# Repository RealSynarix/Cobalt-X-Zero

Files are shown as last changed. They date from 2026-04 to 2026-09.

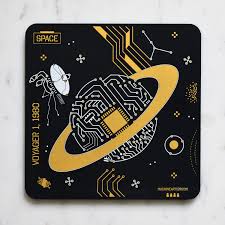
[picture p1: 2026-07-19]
docs/media/images/reference/3.jpg

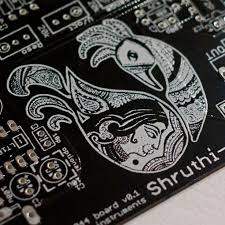
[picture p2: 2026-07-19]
docs/media/images/reference/1.jpg

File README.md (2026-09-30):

# Cobalt-X Zero

**Open-source • 3D-printable • 50g balanced gaming mouse**

Built around the STM32G431 and PixArt PMW3360.  
No bloated software. Configuration lives entirely in the browser via WebHID.

**Config site:** [Click Me :D](https://realsynarix.github.io/Cobalt-X-Zero/)  
Works in Chrome / Edge (desktop). Plug the mouse in, hit **Connect**, create or edit profiles, save.

---

## Why this exists

Most gaming mice force you to install closed, resource-heavy software.  
Cobalt-X Zero does the opposite:

- Fully open hardware & software (PCB, shell, firmware, configurator)
- Zero host-side software required after initial flash (you need software to flash, but then you can close and optionally delete it)
- Lightweight, relatively cheap, and modifiable by design

Ideal for anyone who wants a high-performance mouse without proprietary software and host resources being hogged.

---

## Specs

| Part | Detail |
|---|---|
| **MCU** | STM32G431KBT6 (170 MHz, LQFP-32) |
| **Sensor** | PixArt PMW3360 |
| **Polling** | 1000 Hz USB (8 kHz internal loop + SOF sync) |
| **Click latency**| ~2.5 ms |
| **Weight** | 50 g (without cable) |
| **Switches** | Kailh Mute Push Buttons (red cap, 2 pin + 10M click life-span) |
| **Wheel** | TTC EC10 rotary encoder + custom printed wheel |
| **LEDs** | 2× RGB (Cathode) |
| **Config** | WebHID Github Pages Website |
| **Shell** | Custom PETG 3D Print |

---

## Repository Layout

| Path | Contents |
|---|---|
| `firmware/` | C++ firmware source + pre-built binaries |
| `hardware/fabrication/pcb/` | KiCad project, Gerbers, BOM, position files |
| `hardware/fabrication/shell/` | 3D printable STLs + print settings |
| `docs/guides/` | Assembly, flashing, configuration, and general guides |

---

## Getting Started

1. **Read the docs**  
   Start with [`docs/guides/`](docs/guides/) for assembly instructions, print settings, and firmware details.

2. **Print the shell**  
   Use the STLs and recommended settings in `hardware/fabrication/shell/`.

3. **Order & assemble the PCB**  
   - Fabricate from the Gerbers in `hardware/fabrication/pcb/` (JLCPCB works well).  
   - The PMW3360 sensor must be purchased separately (e.g. AliExpress) and hand-soldered.

4. **Flash the firmware**  
   Follow the flashing guide in `docs/guides/`. Pre-built binaries are available for quick setup; source is there if you want to modify it.

5. **Configure**  
   Open the [config site](https://realsynarix.github.io/Cobalt-X-Zero/), connect the mouse, create profiles, and tune everything to your preference. Multiple profiles are supported.

---

## License & Contributions

Everything in this project is open source.  
You are free to fork, modify, improve, and share your own builds.

**Attribution is appreciated.**  
If you use Cobalt-X Zero commercially or base a project on it, please include a link back to this repository.

Issues and pull requests are always welcome.

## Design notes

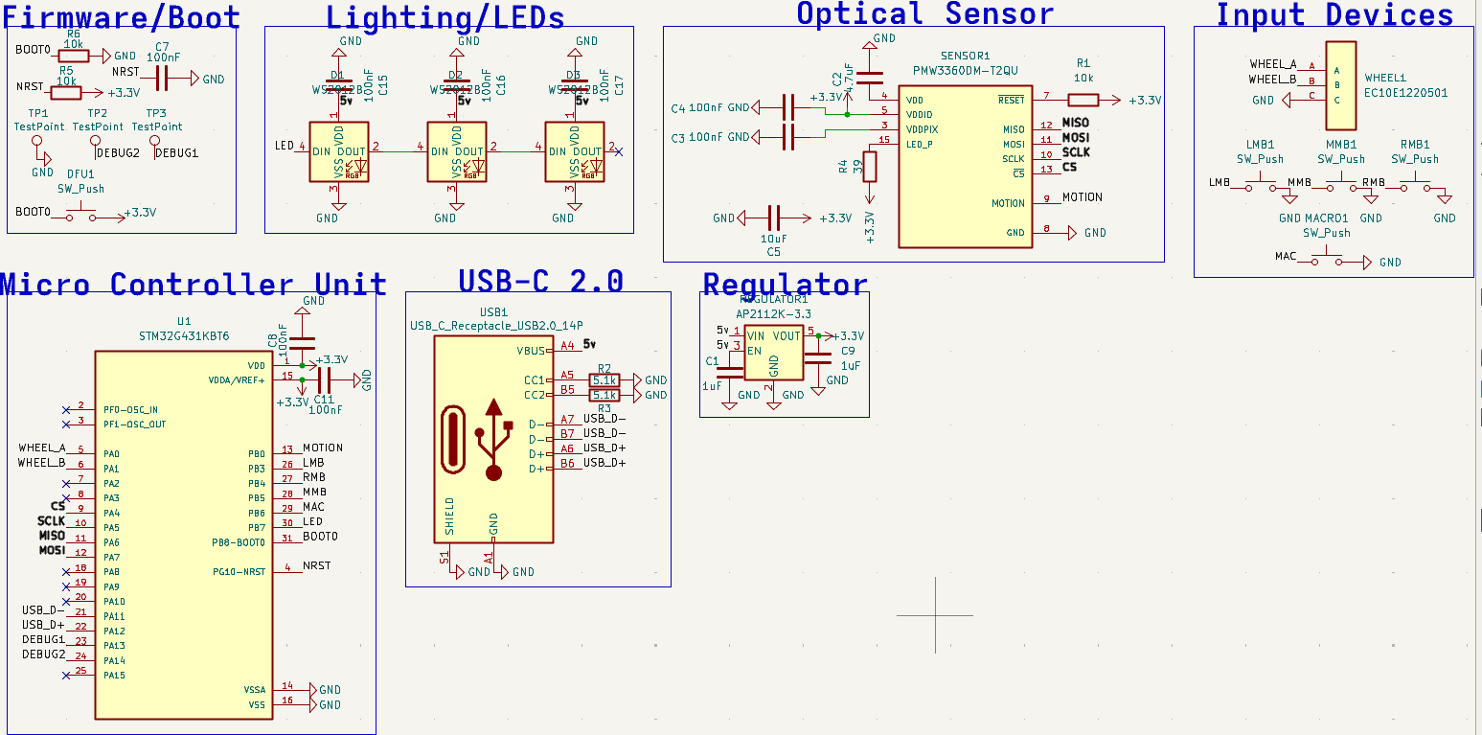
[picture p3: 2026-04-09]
docs/media/images/reference/Proto2-Schematic.png

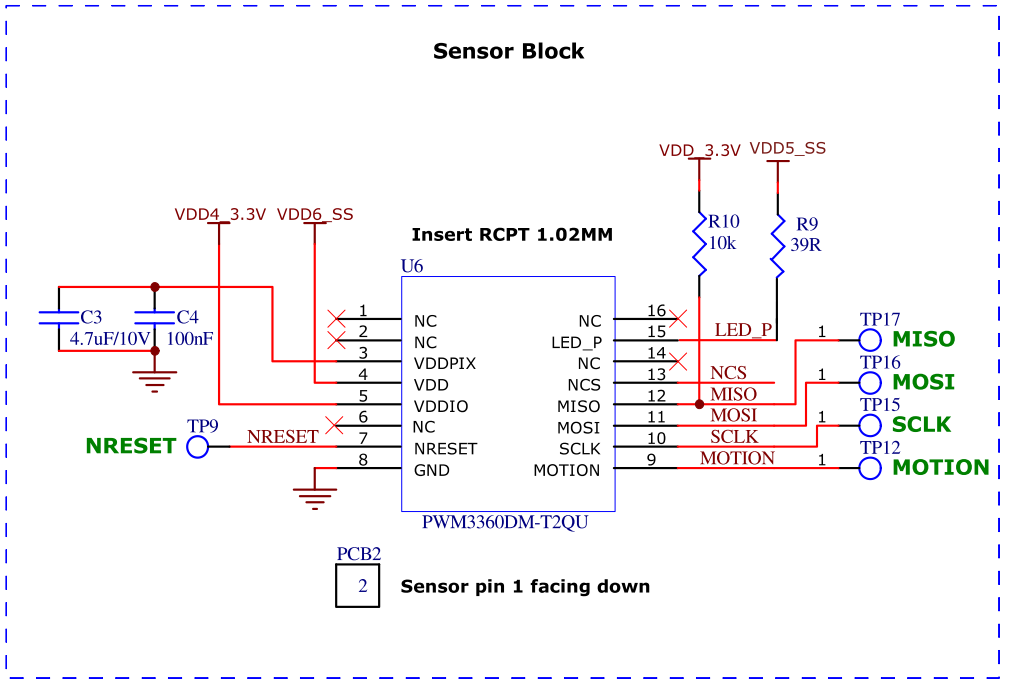
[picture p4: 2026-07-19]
docs/media/images/reference/Sensor-Block-Datasheet-Ref.png

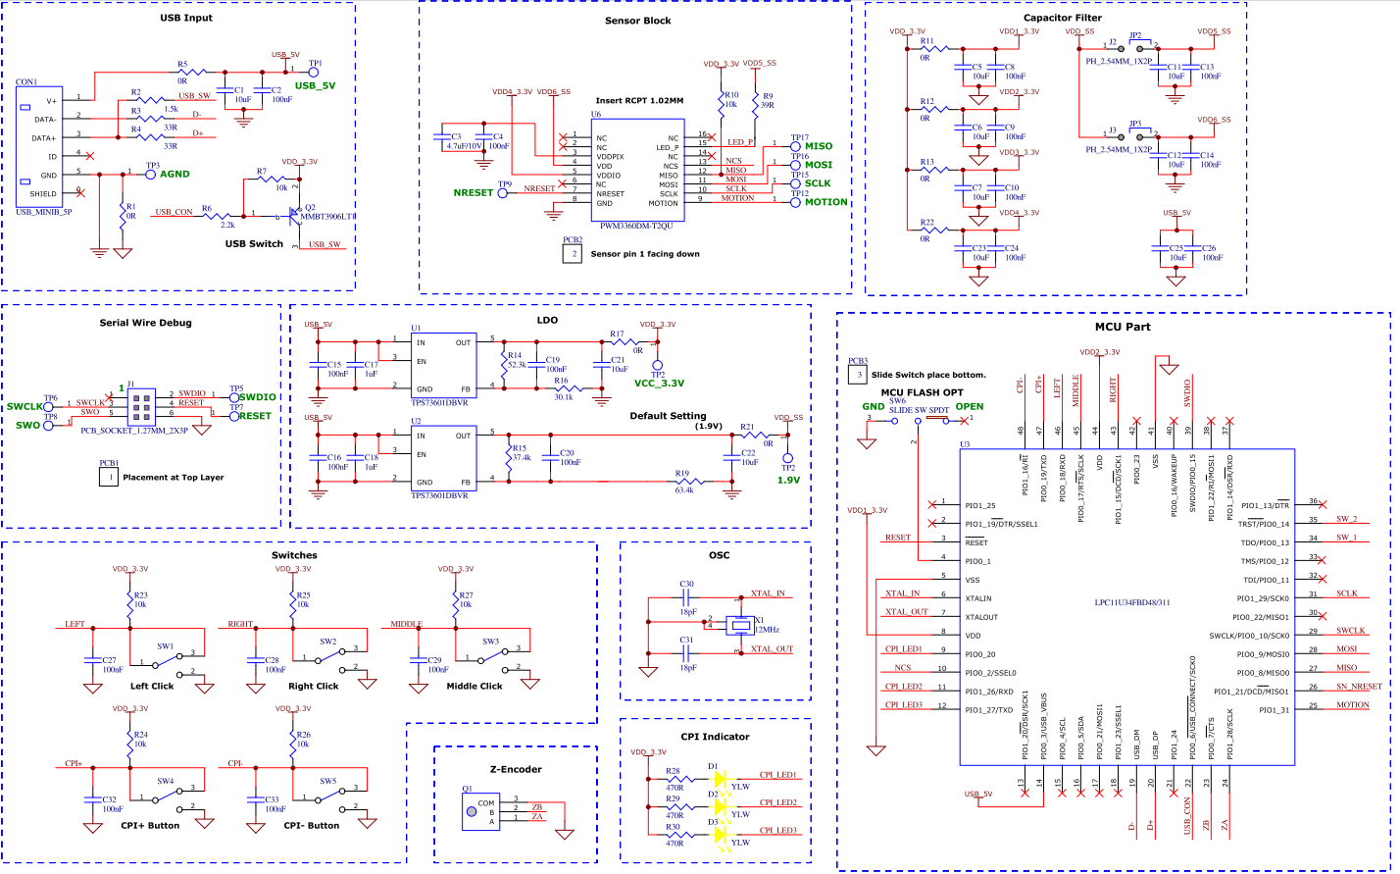
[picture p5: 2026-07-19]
docs/media/images/reference/Sensor-Schem-Datasheet-Ref.png

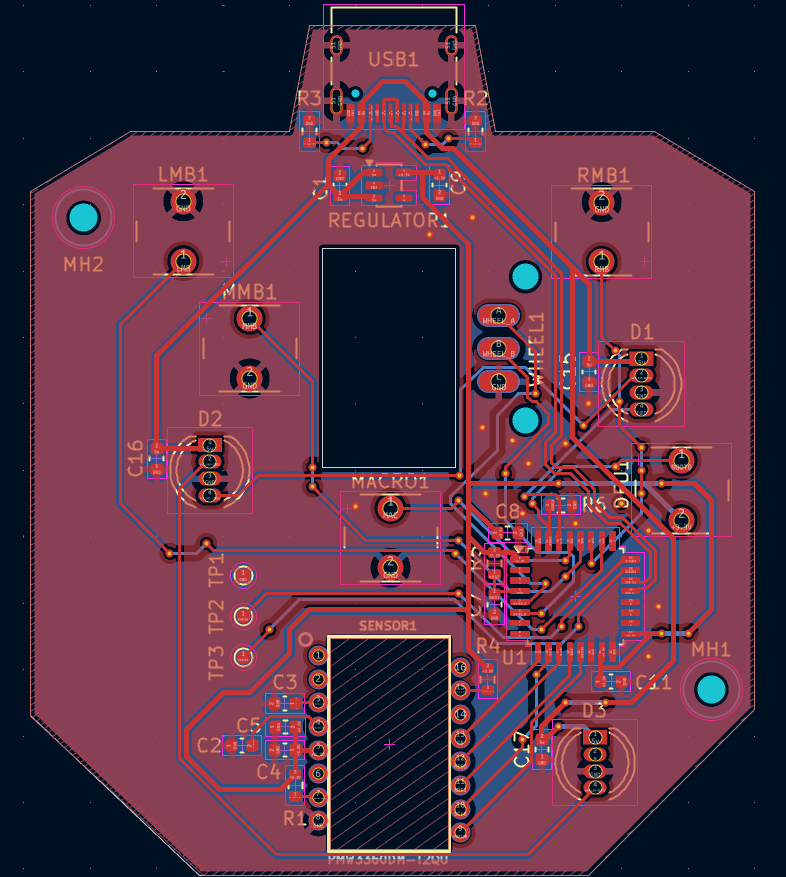
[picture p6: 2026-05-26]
docs/media/images/reference/Proto2.png

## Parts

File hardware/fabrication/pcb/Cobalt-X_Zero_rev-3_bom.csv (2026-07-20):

Designator | Footprint | Quantity | Value | LCSC Part #
C1, C10, C2, C9 | 0603 | 4 | 1uF
C11, C12, C14, C20, C7, C8 | 0603 | 6 | 100nF
C13 | 0603 | 1 | 4.7uF
C17, C3 | 0603 | 2 | 10nF
MCU1 | LQFP-32_7x7mm_P0.8mm | 1 | STM32G431KBT6
R1 | 0603 | 1 | 39
R10, R11, R8, R9 | 0603 | 4 | 33
R12, R13, R14, R15, R16, R17 | 0603 | 6 | 150
R2, R3 | 0603 | 2 | 5.1k
R4, R5, R6 | 0603 | 3 | 10k
R7 | 0603 | 1 | 100k
REG1 | SOT-23-5 | 1 | AP2112K-3.3
REG2 | DBV0005A_N | 1 | TLV75519PDBVR
USB1 | USB_C_Receptacle_HRO_TYPE-C-31-M-12 | 1 | USB_C_Receptacle_USB2.0_14P
WHEEL1 | TRIM_EC10E1220501 | 1 | EC10E1220501

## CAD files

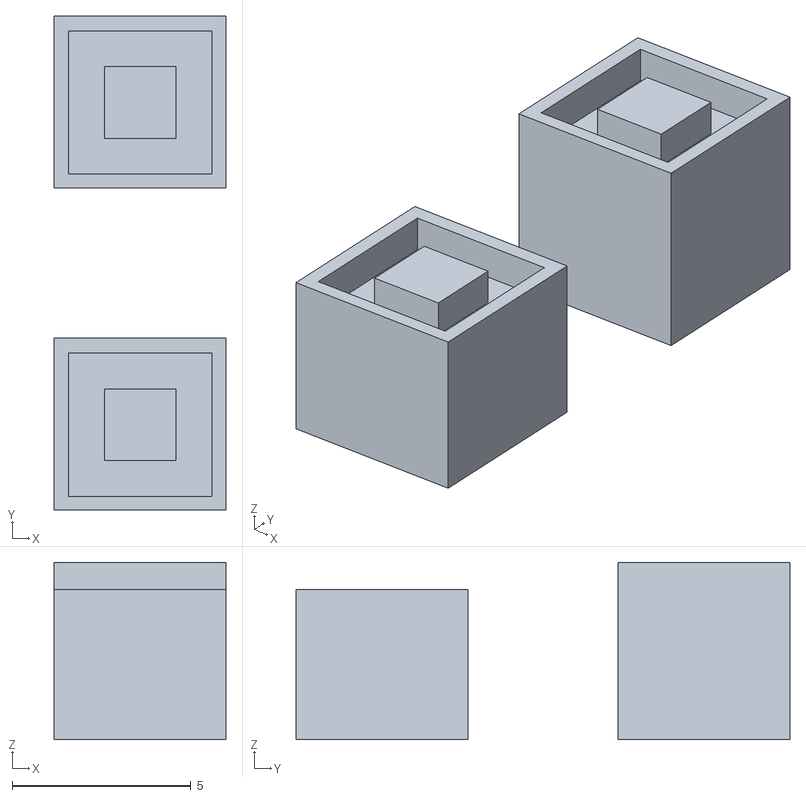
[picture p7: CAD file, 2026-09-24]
hardware/fabrication/shell/Top-Plungers.stl
4.80 x 13.8 x 4.95

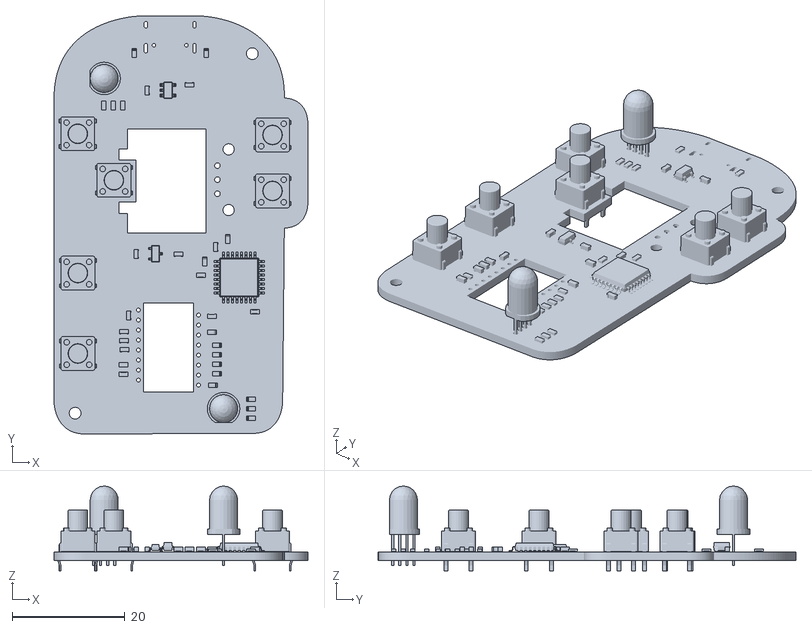
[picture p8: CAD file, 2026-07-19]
hardware/ie-kicad/CustomMouse/.stl
45.1 x 74.3 x 15.1

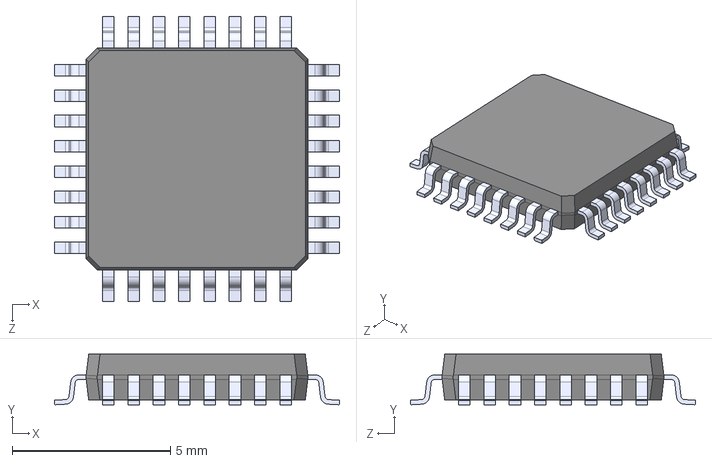
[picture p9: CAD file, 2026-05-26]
hardware/ie-kicad/ImportedComponents/STM32G431KBT6/STM32G431KBT6.step
9.00 x 1.60 x 9.00 mm

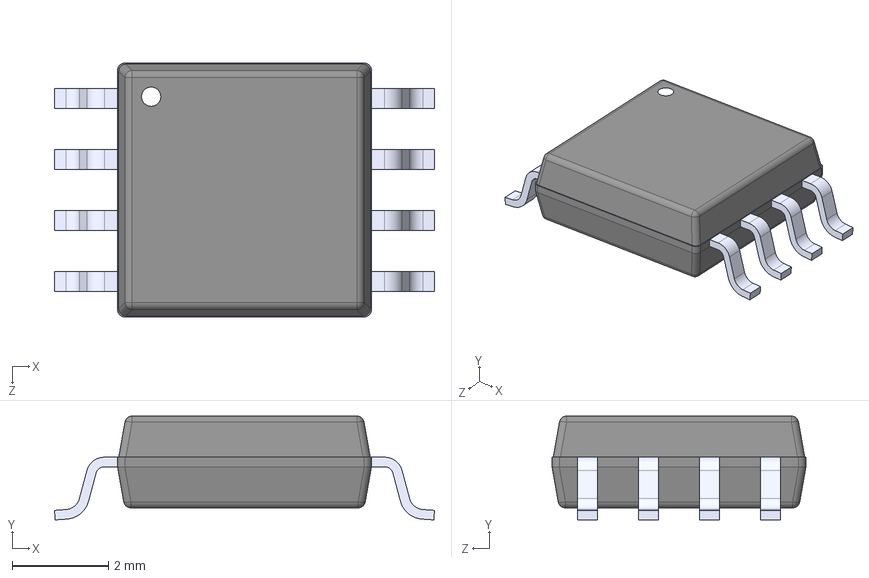
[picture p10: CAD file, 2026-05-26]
hardware/ie-kicad/ImportedComponents/W25Q16JVSSIQ/W25Q16JVSSIQ.step
7.90 x 2.16 x 5.28 mm

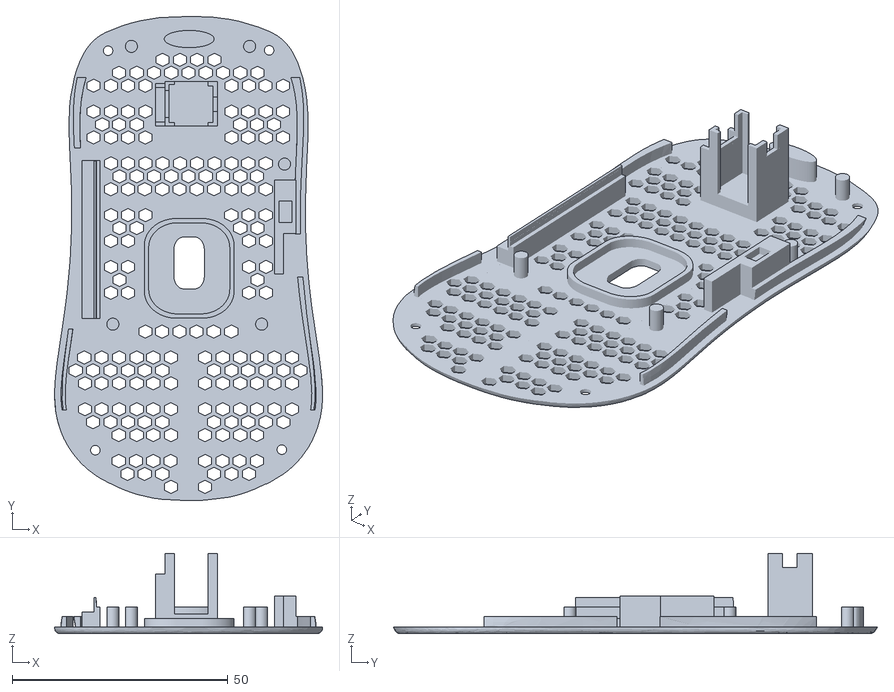
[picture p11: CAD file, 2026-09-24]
hardware/fabrication/shell/Bottom-Plate.stl
62.1 x 112.3 x 18.6

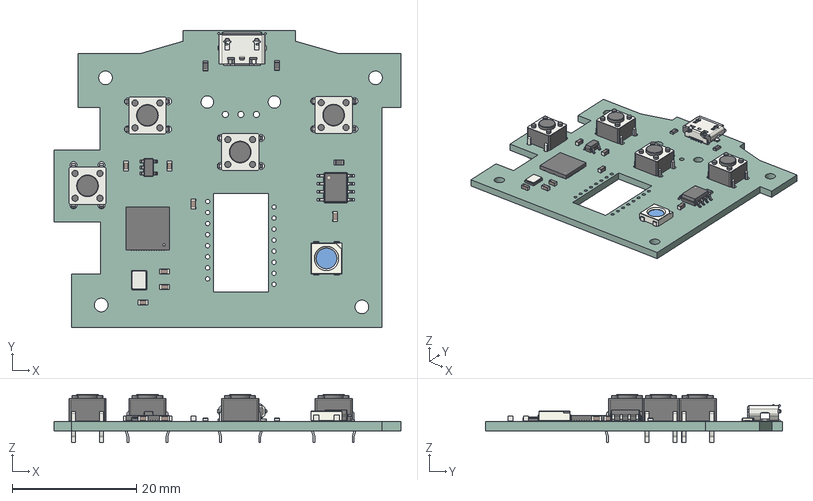
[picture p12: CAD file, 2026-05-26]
hardware/ie-kicad/CustomMouse/CustomMouse.step
55.9 x 47.8 x 7.80 mm
SW_PUSH_6mm_H4.3mm x 4
USB_Micro-B_Molex_47346-0001
C_0603_1608Metric x 7
R_0603_1608Metric x 3
SOIC-8_3.9x4.9mm_P1.27mm
QFN-56-1EP_7x7mm_P0.4mm_EP3.2x3.2mm
Crystal_SMD_3225-4Pin_3.2x2.5mm
LED_WS2812B_PLCC4_5.0x5.0mm_P3.2mm
SOT-23-5
CustomMouse_PCB

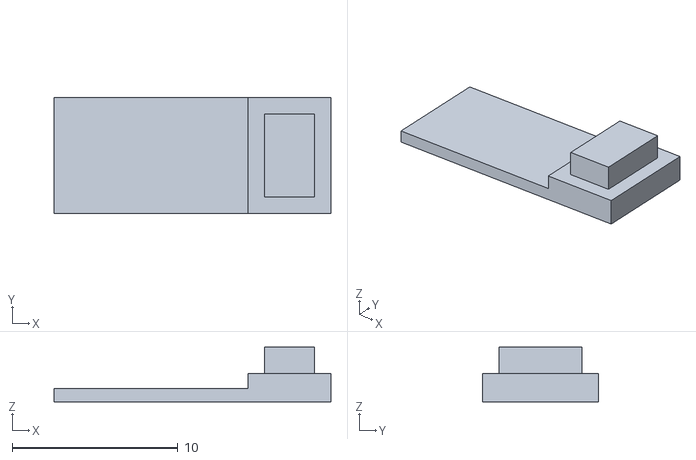
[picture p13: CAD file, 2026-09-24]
hardware/fabrication/shell/PCB-Holder.stl
16.7 x 7.00 x 3.30

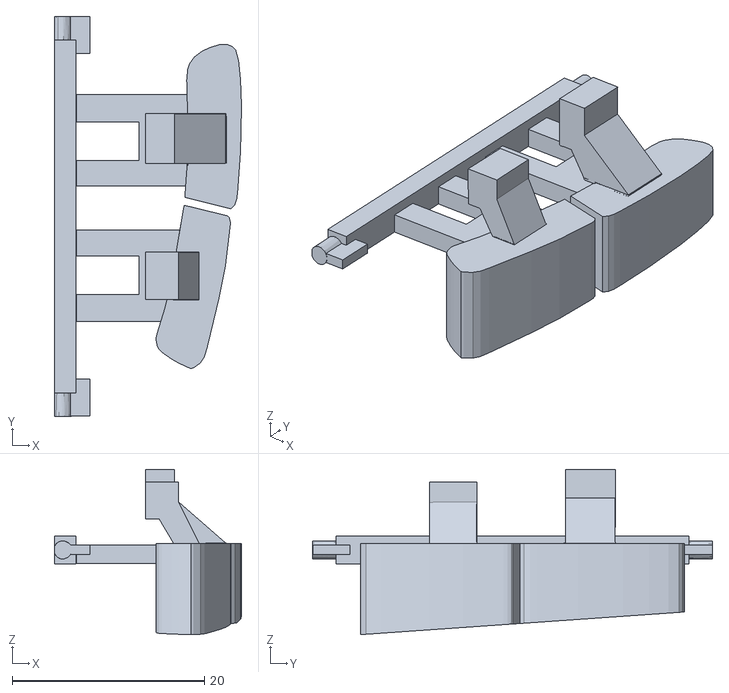
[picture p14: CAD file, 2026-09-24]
hardware/fabrication/shell/Side-Buttons.stl
19.4 x 41.6 x 17.2

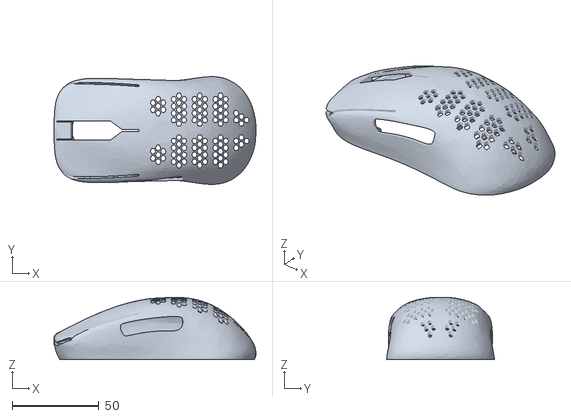
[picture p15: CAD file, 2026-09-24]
hardware/fabrication/shell/Top-Shell.stl
116.5 x 62.1 x 35.8

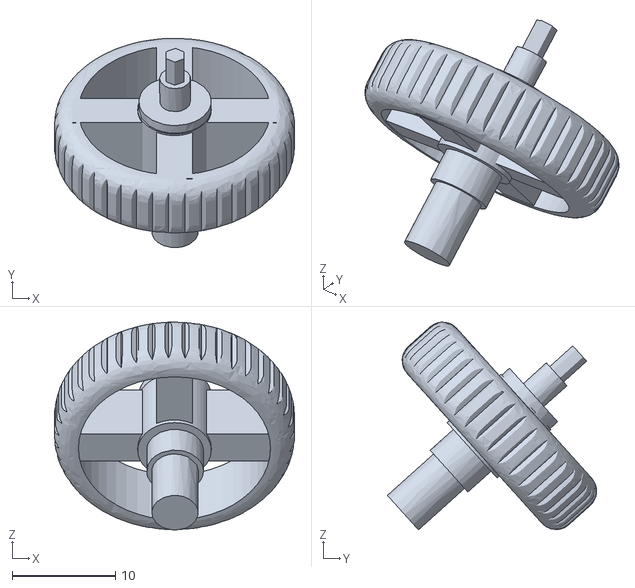
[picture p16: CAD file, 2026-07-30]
hardware/fabrication/shell/Scroll-Wheel.stl
23.2 x 20.2 x 20.1

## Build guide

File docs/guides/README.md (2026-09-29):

# Guides

This folder has the practical guides you actually need to build and use Cobalt-X Zero without wasting time.

| Guide | What it covers |
| --- | --- |
| `main.md` | Index with links to all guides |
| `assembly.md` | Step by step mechanical assembly, PCB holder clip and plunger studs |
| `firmware.md` | How to flash firmware (source vs binaries in `firmware/build/`) and verify it enumerates |
| `configuration.md` | How the WebHID configurator at https://realsynarix.github.io/Cobalt-X-Zero/ works and what each field does |

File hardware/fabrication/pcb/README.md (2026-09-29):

# PCB Fabrication

Files to manufacture and edit PCB.

| File | Purpose |
| --- | --- |
| `Cobalt-X_Zero.kicad_sch` | Schematic |
| `Cobalt-X_Zero.kicad_pcb` | Layout |
| `Cobalt-X_Zero_rev-3.zip` | Gerbers |
| `Cobalt-X_Zero_rev-3_bom.csv` | BOM |
| `positions.csv` | Pick and place |
| `netlist.ipc` | Netlist |

### Order

Upload zip to fab, 4-layer 1.6mm ENIG if possible. Use BOM + positions for partial assembly. Switches and encoder better hand soldered.

### Known issues rev 3

| Issue | Detail | Workaround |
| --- | --- | --- |
| LED pins wrong | Pins swapped in schematic | Re-route or bend legs |
| Sensor noise | SI/EMI near sensor | Firmware filters most, fix would be better grounding and 3.3V routing |

Works as-is.

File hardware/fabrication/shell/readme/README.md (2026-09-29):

# 3D Models - Shell

Everything needed to print shell plus slicer settings and post-processing.

| File | What it is |
| --- | --- |
| `../Bottom-Plate.stl` | Bottom plate with ribs/pockets that prevent wobble and locate PCB |
| `../Top-Shell.stl` | Top shell |
| `../Scroll-Wheel.stl` | Custom wheel for EC10 |
| `../Side-Buttons.stl` | Side buttons |
| `../Top-Plungers.stl` | Plungers and studs |
| `../PCB-Holder.stl` | Small clip that goes on top of bottom shell near MCU hole, holds board down so it won't lift |
| `settings.txt` | Slicer settings |
| `post-processing.txt` | Cleaning and fit |
| `README.md` | This file |

### PCB holder and bottom shell

Bottom shell has integrated ribs and pockets that hold PCB and stop wobble side to side. PCB holder is separate small clip on top of bottom shell that presses board down so it won't lift up and down. Test upside down, board should not move.

### Plunger studs

Plungers include little ~2mm blocks that clip onto underside of top shell into 2 holes under 2 large plungers. Those are what clicks onto mechanical switches for LMB/RMB. Shortest stud is RMB, longest is LMB. Push into slots clearly visible. May be deprecated later but rev 3 needs them.

### How I modelled these

I'm extremely happy with how these turned out. I practically mastered TinkerCAD just doing this project alone. I didn't use Blender or Fusion. I used specific shaped cutouts, the sketch tool to get exact profiles, and like 100ish hole objects layered on the baseplate to get curves and clearances right. It sounds messy but it works and final fit is tight.

### Print info

| Setting | Value |
| --- | --- |
| Material | PETG |
| Layer | 0.25mm first 0.35mm |
| Infill | 9% |
| Support | Tree auto |
| Brim | None |
| Fuzzy | Off |

Follow settings.txt and post-processing.txt, then docs/guides/assembly.md. Flash from firmware/build/ before closing top shell. Test at https://realsynarix.github.io/Cobalt-X-Zero/.

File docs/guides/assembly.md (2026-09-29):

# Assembly Guide

How to put Cobalt-X Zero together from PCB and printed parts. Flash firmware before you close the top shell, you can't reach DFU button after.

Config site for testing: https://realsynarix.github.io/Cobalt-X-Zero/

### What you need

**PCB side:**
- Board fabricated from `hardware/fabrication/pcb/Cobalt-X_Zero_rev-3.zip`
- All parts from BOM soldered
- USB cable with Type-C on one end, data cable not power-only

**Shell side:**
- Printed parts: Bottom-Plate, Top-Shell, Scroll-Wheel, Side-Buttons, Top-Plungers (includes studs), PCB-Holder
- 4x small screws
- 4x 0.75mm PTFE skates
- Scroll wheel, side buttons
- Grip tape
- Sensor lens

Make sure prints are post-processed per `hardware/fabrication/shell/readme/post-processing.txt`.

### Steps

| Step | Action |
| --- | --- |
| 1 | **Lens** - Press lens firmly into bottom plate until even and it snaps. Check orientation. If PCB later won't sit snug, lens is 180 degrees off, flip it. |
| 2 | **Scroll wheel** - Push scroll wheel firmly into rotary encoder on PCB. You may need to flex encoder to side slightly, it won't break or bend. |
| 3 | **PCB into bottom** - Slot PCB into bottom shell. It should fit very tightly once slid in. Align with scroll wheel, there are alignment helpers in bottom plate that stop wobble side to side. |
| 4 | **PCB holder** - PCB holder is a small clip that goes on top of bottom shell and holds board onto shell so it won't lift up and down. Bottom shell has features that hold it and prevent wobbling. Push holder down onto hole on side of bottom plate near MCU. It should click and hold MCU. Test by flipping upside down, board should not move. |
| 5 | **Studs** - Studs are little ~2mm blocks that clip onto underside of top shell. They are what clicks onto mechanical switches for LMB/RMB. Get top shell and studs and push them into slots, clearly visible underside of 2 large plungers, 2 holes. Shortest stud is RMB, longest is LMB. They may be deprecated later, but rev 3 needs them. |
| 6 | **Flash firmware** - MUST flash before top shell. You cannot access DFU button after top shell assembled. Source in `firmware/source` for dev, binaries in `firmware/build/` for consumer. See `firmware.md`. |
| 7 | **Close shells** - Flip top shell right way, bottom shell with all its stuff in other hand. Tilt bottom so USB/front is tilted up and back slightly down, then align horizontally and vertically and push forward, leaning down so it evens out. It should clip in, then move slightly to snug it more. |
| 8 | **Screws** - Flip over and screw in 4 holes. You may need to move top shell slightly to line up. |
| 9 | **Tighten** - Screws must be very tight. Looking from side, they should not extrude, they should be flush as part of bottom shell surface. |
| 10 | **Skates** - Stick PTFE skates right on top of screws, covering them. |
| 11 | **Grip tape** - Cut to how you like and stick on LMB big plunger, RMB big plunger, under side buttons, and other side of top shell side button area, ring finger rest. |
| 12 | **Done** - Plug cable into mouse then PC. Should enumerate as Synarix Cobalt-X Zero. Open https://realsynarix.github.io/Cobalt-X-Zero/ to test. |

### Notes

| Point | Detail |
| --- | --- |
| Lens | If PCB doesn't sit flat, lens is backwards |
| PCB holder | Small clip on top of bottom shell, holds down, test upside down |
| Bottom shell | Has ribs/pockets to stop wobble |
| Studs | ~2mm blocks under top shell, shortest RMB longest LMB |
| DFU | Only accessible before top shell |
| Screws | Must be flush or skates won't sit flat |

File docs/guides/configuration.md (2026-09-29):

# Configuration Guide

Mouse configured in browser via WebHID. No app.

Site: https://realsynarix.github.io/Cobalt-X-Zero/

### Access

| Step | Action |
| --- | --- |
| 1 | Chrome or Edge desktop, Firefox and Safari don't support WebHID |
| 2 | Open https://realsynarix.github.io/Cobalt-X-Zero/ |
| 3 | Plug mouse, click Connect, pick Cobalt-X Zero |
| 4 | Ping, Re-Read All, edit, Save Changed |

### FIDs

Stored at 0x0801F800 with CRC32.

| FID | Name | Type | Purpose |
| --- | --- | --- | --- |
| 1 | device_name | string 31 | OS name |
| 2 | manufacturer | string 31 | Default Synarix |
| 3 | serial | string 15 | Serial |
| 4 | fw_version | string 15 | 0.9.2 read-only |
| 16-21 | mod flags | bool | Enable modules |
| 32 | dpi | u16 | 100-32000 |
| 33 | poll | u16 | 125,250,500,1000,2000,4000,8000 |
| 34 | lod_mm | u8 | 1-3 |
| 35 | lod_squal | u8 | 10-200, default 20 |
| 36 | angle_snap | bool | Snap |
| 37 | angle_strength | u8 | 0-100 |
| 38 | surface | u8 | 0-3 |
| 48-52 | debounce | u8 | 0-20ms per PB |
| 53 | click_mode | u8 | 0-2 |
| 64 | wheel_div | u8 | 1-8 default 3 |
| 65 | wheel_inv | bool | Invert |
| 66 | wheel_smooth | bool | Smooth |
| 80-85 | hyprx | mixed | HyprX engine |
| 96 | led_def | rgb | Default #0A5BD7 |
| 97 | led_macro | rgb | Macro |
| 98 | led_bri | u8 | 0-255 brightness |
| 99 | led_eff | u8 | 0 solid 1 breathing 2 blink 3 rainbow 4 chase |
| 100 | led_speed | u8 | Speed |
| 112-117 | pb7 | mixed | PIO button modes |

Minimal firmware: only 1,2,33,96-100 visibly affect hardware, rest stored.

Factory Reset writes defaults. Profiles in localStorage. Config site hosted at https://realsynarix.github.io/Cobalt-X-Zero/.

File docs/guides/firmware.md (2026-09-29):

# Firmware Guide

### Where firmware lives

| Path | What it is |
| --- | --- |
| `firmware/source` | Full C++ source version for development. Flash this if you want to edit, debug, or build custom features. Recommended for dev. |
| `firmware/build/` | Built binaries inside this folder. Flash a binary from here for normal consumer use, no toolchain needed. Recommended for consumer. |

Either works. Dev should flash source, consumer should flash a binary from `firmware/build/`.

### Requirements

| Item | Detail |
| --- | --- |
| For source | Arduino IDE 2.x, STM32 core 3.0.0+, Generic STM32G4 G431KBT6 170MHz |
| For binary | STM32CubeProgrammer or dfu-util |
| Cable | USB-C data cable |

### Flash source

| Step | Action |
| --- | --- |
| 1 | Open `current.ino` from `firmware/source` |
| 2 | Check `build_opt.h` has `-DHAL_PCD_MODULE_ENABLED -DUSBD_USE_HID_COMPOSITE=1 -DUSBD_USE_CUSTOM_HID=1 -DUSBD_VID=0x1209 -DUSBD_PID=0xC0BA -include src/USB-Module/descriptors.h` |
| 3 | Put board in DFU if needed, upload |

### Flash binary from firmware/build/

| Step | Action |
| --- | --- |
| 1 | DFU mode: hold BOOT0 while plugging |
| 2 | Open STM32CubeProgrammer, select USB |
| 3 | Browse to a binary inside `firmware/build/`, e.g. `Cobalt-X_Zero.bin` or `firmware_here.bin` |
| 4 | Start address `0x08000000`, check Verify + Run after programming |
| 5 | Flash, unplug/replug |

### Verification

| Check | Expected |
| --- | --- |
| lsusb | VID 0x1209 PID 0xC0BA Synarix Cobalt-X Zero |
| Chrome HID | Shows Cobalt-X Zero usage page 0xFF00 at https://realsynarix.github.io/Cobalt-X-Zero/ |
| Config site | Connect -> Ping -> Re-Read All works |
| LEDs | Blue breathing after flash |

### Troubleshooting

| Issue | Fix |
| --- | --- |
| Generic / HyprX Device | descriptors.h not included |
| No device | Check HSI48 + CRS, data cable |
| Chrome not showing | Use Chrome/Edge desktop, check navigator.hid |

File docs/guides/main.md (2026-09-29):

# Cobalt-X Zero - Guides Index

Entry point for all documentation.

| File | Purpose |
| --- | --- |
| [README.md](./README.md) | Overview |
| [assembly.md](./assembly.md) | Full assembly: PCB, lens, wheel, holder clip, studs, closing, screws, skates, grip tape |
| [firmware.md](./firmware.md) | Flash source in `firmware/source` or binaries in `firmware/build/` |
| [configuration.md](./configuration.md) | Config site https://realsynarix.github.io/Cobalt-X-Zero/ usage and FID table |

| Path | Purpose |
| --- | --- |
| `../../README.md` | Project overview |
| `../../hardware/fabrication/pcb/README.md` | PCB fab and known issues |
| `../../hardware/fabrication/shell/readme/README.md` | Print settings, PCB holder, studs, TinkerCAD notes |

1. Read README in this folder.
2. Follow assembly.md but flash before top shell.
3. Follow firmware.md.
4. Follow configuration.md at https://realsynarix.github.io/Cobalt-X-Zero/.

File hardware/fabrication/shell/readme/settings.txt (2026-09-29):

Material           - PETG
Layer Height       - 0.25 mm
First Layer Height - 0.35 mm
Infill Density     - 9 %
Support            - Tree (auto)
Brim               - None
Fuzzy Skin         - Off
Wall Count         - 3
Top Layers         - 4
Bottom Layers      - 4
Print Speed        - 45 mm/s outer, 60 mm/s inner
Nozzle Temp        - 235C
Bed Temp           - 75C
Retraction         - 4.5mm at 40mm/s

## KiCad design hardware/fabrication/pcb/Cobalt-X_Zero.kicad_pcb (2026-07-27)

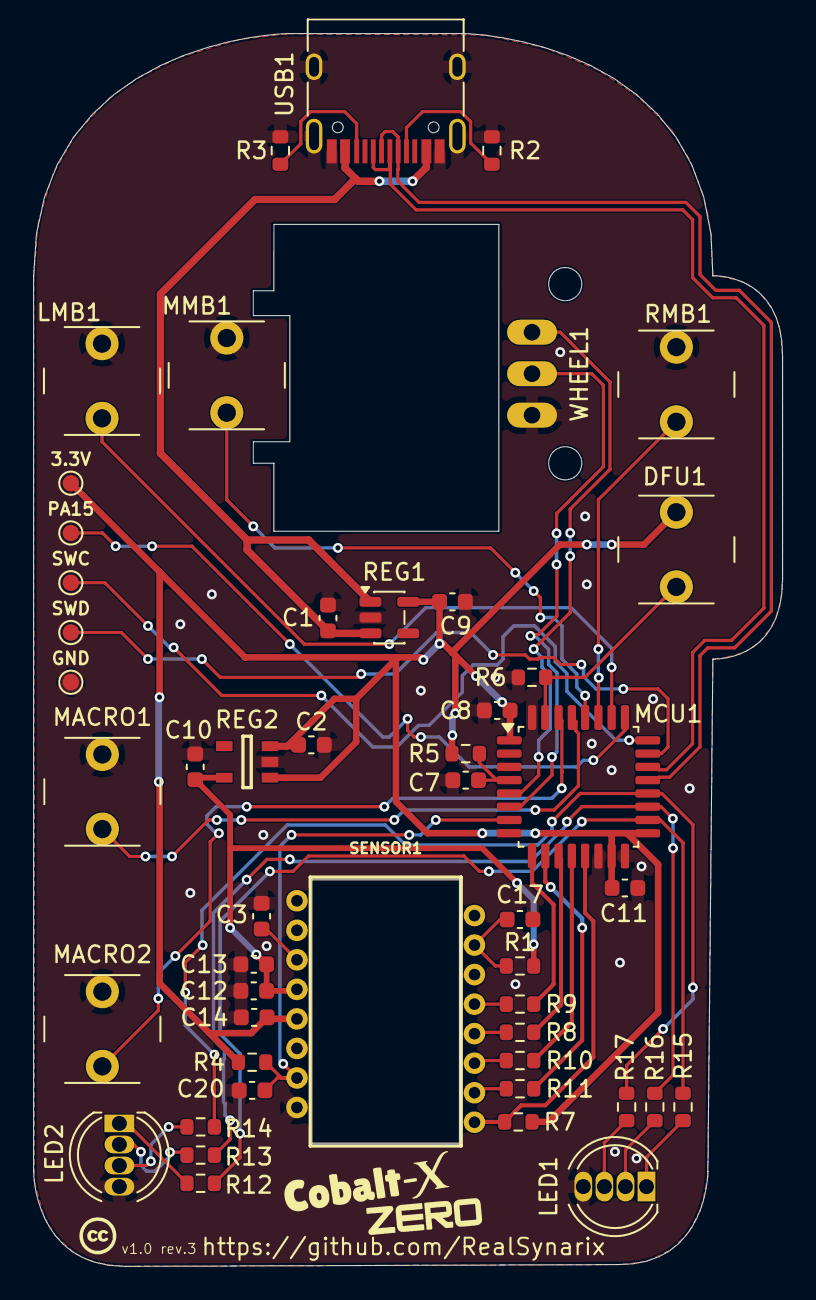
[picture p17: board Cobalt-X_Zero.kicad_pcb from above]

Board: 2 copper layers, 45.1 x 74.3 mm, 49 parts (0 on the bottom side), 41 nets.

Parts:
3.3V: TestPoint_Probe; TestPoint_Pad_D1.0mm
C1, C2, C9, C10: 1uF; C_0603_1608Metric
C3, C17: 10nF; C_0603_1608Metric
C7, C8, C11, C12, C14, C20: 100nF; C_0603_1608Metric
C13: 4.7uF; C_0603_1608Metric
DFU1: SW_Push; SW_PUSH_6mm_H7.3mm_2-Pin
GND: TestPoint_Probe; TestPoint_Pad_D1.0mm
LED1, LED2: LED_RGBA; LED_D5.0mm-4_RGB
LMB1: SW_Push; SW_PUSH_6mm_H7.3mm_2-Pin
MACRO1, MACRO2: SW_Push; SW_PUSH_6mm_H7.3mm_2-Pin
MCU1: STM32G431KBT6; LQFP-32_7x7mm_P0.8mm
MMB1: SW_Push; SW_PUSH_6mm_H7.3mm_2-Pin
PA15: TestPoint_Probe; TestPoint_Pad_D1.0mm
R1: 39; R_0603_1608Metric
R2, R3: 5.1k; R_0603_1608Metric
R4, R5, R6: 10k; R_0603_1608Metric
R7: 100k; R_0603_1608Metric
R8, R9, R10, R11: 33; R_0603_1608Metric
R12, R13, R14, R15, R16, R17: 150; R_0603_1608Metric
REG1: AP2112K-3.3; SOT-23-5
REG2: TLV75519PDBVR; DBV0005A_N
RMB1: SW_Push; SW_PUSH_6mm_H7.3mm_2-Pin
SENSOR1: PMW3360DM-T2QU; PMW3360
SWC: TestPoint_Probe; TestPoint_Pad_D1.0mm
SWD: TestPoint_Probe; TestPoint_Pad_D1.0mm
USB1: USB_C_Receptacle_USB2.0_14P; USB_C_Receptacle_HRO_TYPE-C-31-M-12
WHEEL1: EC10E1220501; TRIM_EC10E1220501

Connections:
+1.9v: C10.1, C12.1, C13.1, R1.2, REG2.5 (OUT), SENSOR1.4 (VDD)
+3.3V: 3.3V.1 (1_1), C2.1, C8.1, C9.1, C11.1, C14.2, DFU1.2, MCU1.1 (VDD), MCU1.15 (VDDA/VREF+), MCU1.17 (VDD), R4.2, R5.2, R7.2, REG1.5 (VOUT), REG2.1 (IN), REG2.3 (EN), SENSOR1.5 (VDDIO)
+5v: C1.1, REG1.1 (VIN), REG1.3 (EN), USB1.A4 (VBUS), USB1.A9 (VBUS), USB1.B4 (VBUS), USB1.B9 (VBUS)
/BLUE: MCU1.20 (PA10), R14.1, R17.1
/BOOT0: DFU1.1, MCU1.31 (PB8-BOOT0), R6.1
/CS: MCU1.9 (PA4), R9.2
/GREEN: MCU1.19 (PA9), R13.1, R16.1
/LMB: LMB1.1, MCU1.26 (PB3)
/MAC1: MACRO1.1, MCU1.29 (PB6)
/MAC2: MACRO2.1, MCU1.30 (PB7)
/MISO: MCU1.11 (PA6), R8.2
/MMB: MCU1.28 (PB5), MMB1.1
/MOSI: MCU1.12 (PA7), R10.2
/MOTION: MCU1.13 (PB0), R7.1, SENSOR1.9 (MOTION)
/NRST: C7.1, MCU1.4 (PG10-NRST), R5.1
/PA15: MCU1.25 (PA15), PA15.1 (1_1)
/RED: MCU1.18 (PA8), R12.1, R15.1
/RMB: MCU1.27 (PB4), RMB1.1
/SCLK: MCU1.10 (PA5), R11.2
/SRST: C20.2, MCU1.7 (PA2), R4.1, SENSOR1.7 (~RESET)
/SWCLK: MCU1.24 (PA14), SWC.1 (1_1)
/SWDIO: MCU1.23 (PA13), SWD.1 (1_1)
/USB_D+: MCU1.22 (PA12), USB1.A6 (D+), USB1.B6 (D+)
/USB_D-: MCU1.21 (PA11), USB1.A7 (D-), USB1.B7 (D-)
/WHEEL_A: MCU1.5 (PA0), WHEEL1.A
/WHEEL_B: MCU1.6 (PA1), WHEEL1.B
GND: C1.2, C2.2, C3.2, C7.2, C8.2, C9.2, C10.2, C11.2, C12.2, C13.2, C14.1, C17.1, C20.1, GND.1 (1_1), LED1.4 (A), LED2.4 (A), LMB1.2, MACRO1.2, MACRO2.2, MCU1.14 (VSSA), MCU1.16 (VSS), MCU1.32 (VSS), MMB1.2, R2.2, R3.2, R6.2, REG1.2 (GND), REG2.2 (GND), RMB1.2, SENSOR1.8 (GND), USB1.A1 (GND), USB1.A12 (GND), USB1.B1 (GND), USB1.B12 (GND), USB1.S1 (SHIELD), WHEEL1.C
unnamed: LED1.3 (BK), R17.2
unnamed: LED1.2 (GK), R16.2
unnamed: LED1.1 (RK), R15.2
unnamed: LED2.3 (BK), R14.2
unnamed: LED2.2 (GK), R13.2
unnamed: LED2.1 (RK), R12.2
unnamed: C17.2, R1.1, SENSOR1.15 (LED_P)
unnamed: R8.1, SENSOR1.12 (MISO)
unnamed: R10.1, SENSOR1.11 (MOSI)
unnamed: R11.1, SENSOR1.10 (SCLK)
unnamed: C3.1, SENSOR1.3 (VDDPIX)
unnamed: R9.1, SENSOR1.13 (~CS)
unnamed: R2.1, USB1.A5 (CC1)
unnamed: R3.1, USB1.B5 (CC2)

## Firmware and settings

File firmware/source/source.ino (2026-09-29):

#include "src/MCU-Module/clock.h"
#include "src/MCU-Module/scheduler.h"
#include "src/USB-Module/device.h"
#include "src/USB-Module/hid.h"
#include "src/Input-Module/tactile.h"
#include "src/Lights-Module/indicator.h"
#include "src/HyprX-Module/engine.h"
#include "src/Config-Module/config.h"
#include "src/Sensor-Module/sensor.h"

static uint32_t last_ind=0;
static uint8_t last_buttons=0;

void setup(void){
  clock_init();
  config_init();
  tactile_init();
  indicator_init();
  hid_init();
  sensor_init();
  usb_device_init();
  scheduler_init();
}

void loop(void){
  for(;;){
    usb_device_poll();
    sensor_task();
    hid_task();
    if(hid_slot()){
      tactile_report_t tr={0,0,0};
      uint8_t has=tactile_pop(&tr);
      int16_t dx,dy; sensor_take(&dx,&dy);
      if(has){
        if(tr.macro) hid_type_program_me();
        last_buttons=tr.buttons;
        hid_send(last_buttons, tr.wheel, dx, dy);
      }else{
        hid_send(last_buttons, 0, dx, dy);
      }
    }
    hid_service();
    uint32_t now=millis();
    if(now-last_ind>=20){ last_ind=now; indicator_tick(); }
  }
}

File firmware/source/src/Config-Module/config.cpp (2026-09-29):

#include "config.h"
#include <string.h>
#include <stm32g4xx_hal.h>
config_t g_cfg;
static uint32_t table[256];
static void crc_init(void){
for(uint32_t i=0;i<256;i++){
uint32_t c=i;
for(int j=0;j<8;j++)c=(c&1)?(0xEDB88320u^(c>>1)):(c>>1);
table[i]=c;
}
}
uint32_t config_crc32(uint8_t *d,uint32_t l){
uint32_t c=0xFFFFFFFFu;
for(uint32_t i=0;i<l;i++)c=table[(c^d[i])&0xFF]^(c>>8);
return c^0xFFFFFFFFu;
}
static void defaults(void){
memset(&g_cfg,0,sizeof(g_cfg));
strncpy(g_cfg.device_name,"Cobalt-X Zero",31);
strncpy(g_cfg.manufacturer,"Synarix",31);
strncpy(g_cfg.serial,"CXZ-000001",15);
strncpy(g_cfg.fw_version,"1.0.0",15);
g_cfg.vid=0x1209;
g_cfg.pid=0xC0BA;
g_cfg.mod_sensor=1;
g_cfg.mod_buttons=1;
g_cfg.mod_scroll=1;
g_cfg.mod_hyprx=1;
g_cfg.mod_leds=1;
g_cfg.mod_sof=1;
g_cfg.dpi=800;
g_cfg.poll=1000;
g_cfg.lod_mm=2;
g_cfg.lod_squal=20;
g_cfg.angle_snap=0;
g_cfg.angle_strength=0;
g_cfg.surface=0;
g_cfg.db_pb3=0;
g_cfg.db_pb4=0;
g_cfg.db_pb5=0;
g_cfg.db_pb6=0;
g_cfg.db_pb7=0;
g_cfg.click_mode=0;
g_cfg.wheel_div=3;
g_cfg.wheel_inv=0;
g_cfg.wheel_smooth=1;
g_cfg.hyprx_en=1;
g_cfg.hyprx_led=1;
g_cfg.hyprx_target=0;
g_cfg.hyprx_stc=1;
g_cfg.hyprx_div=1;
g_cfg.hyprx_hold=0;
g_cfg.led_def[0]=0x00;
g_cfg.led_def[1]=0x00;
g_cfg.led_def[2]=0xFF;
g_cfg.led_macro[0]=0xFF;
g_cfg.led_macro[1]=0xFF;
g_cfg.led_macro[2]=0x00;
g_cfg.led_bri=255;
g_cfg.led_eff=1;
g_cfg.led_speed=100;
g_cfg.pb7_mode=0;
g_cfg.pb7_at=0;
g_cfg.pb7_mouse=0;
g_cfg.pb7_key=0;
g_cfg.pb7_combo_len=0;
g_cfg.pb7_media=0;
g_cfg.config_version=CONFIG_VERSION;
}
int config_reset_defaults(void){defaults();return 0;}
void config_init(void){crc_init();defaults();config_load();}
#define FLASH_CFG_ADDR 0x0801F800
#define FLASH_PAGE_SIZE 0x800
static int flash_erase(uint32_t addr){
HAL_FLASH_Unlock();
__HAL_FLASH_CLEAR_FLAG(FLASH_FLAG_ALL_ERRORS);
FLASH_EraseInitTypeDef e={};
e.TypeErase=FLASH_TYPEERASE_PAGES;
e.Banks=FLASH_BANK_1;
e.Page=(addr-0x08000000)/FLASH_PAGE_SIZE;
e.NbPages=1;
uint32_t err=0;
__disable_irq();
int r=HAL_FLASHEx_Erase(&e,&err)==HAL_OK?0:-1;
__enable_irq();
HAL_FLASH_Lock();
return r;
}
static int flash_write(uint32_t addr,uint8_t *data,uint32_t len){
HAL_FLASH_Unlock();
__HAL_FLASH_CLEAR_FLAG(FLASH_FLAG_ALL_ERRORS);
int r=0;
__disable_irq();
for(uint32_t i=0;i<len&&!r;i+=8){
uint64_t d=~0ull;
for(uint32_t j=0;j<8&&i+j<len;j++){
d&=~(0xFFull<<(j*8));
d|=((uint64_t)data[i+j])<<(j*8);
}
if(HAL_FLASH_Program(FLASH_TYPEPROGRAM_DOUBLEWORD,addr+i,d)!=HAL_OK)r=-1;
}
__enable_irq();
HAL_FLASH_Lock();
return r;
}
int config_save(void){
g_cfg.crc32=0;
uint32_t crc=config_crc32((uint8_t*)&g_cfg,sizeof(g_cfg)-4);
g_cfg.crc32=crc;
if(flash_erase(FLASH_CFG_ADDR)!=0)return -1;
if(flash_write(FLASH_CFG_ADDR,(uint8_t*)&g_cfg,sizeof(g_cfg))!=0)return -1;
return 0;
}
int config_load(void){
config_t *p=(config_t*)FLASH_CFG_ADDR;
if(p->config_version!=CONFIG_VERSION)return -1;
uint32_t stored=p->crc32;
config_t tmp;
memcpy(&tmp,p,sizeof(tmp));
tmp.crc32=0;
uint32_t calc=config_crc32((uint8_t*)&tmp,sizeof(tmp)-4);
if(calc!=stored)return -1;
memcpy(&g_cfg,p,sizeof(g_cfg));
return 0;
}
int config_set_field(uint8_t fid,uint8_t *data,uint16_t len){
if(!data||len>60)return -1;
switch(fid){
case 1:{if(len>31)return -1;memset(g_cfg.device_name,0,32);memcpy(g_cfg.device_name,data,len);return 0;}
case 2:{if(len>31)return -1;memset(g_cfg.manufacturer,0,32);memcpy(g_cfg.manufacturer,data,len);return 0;}
case 3:{if(len>15)return -1;memset(g_cfg.serial,0,16);memcpy(g_cfg.serial,data,len);return 0;}
case 4:{if(len>15)return -1;memset(g_cfg.fw_version,0,16);memcpy(g_cfg.fw_version,data,len);return 0;}
case 16:if(len!=1||data[0]>1)return -1;g_cfg.mod_sensor=data[0];return 0;
case 17:if(len!=1||data[0]>1)return -1;g_cfg.mod_buttons=data[0];return 0;
case 18:if(len!=1||data[0]>1)return -1;g_cfg.mod_scroll=data[0];return 0;
case 19:if(len!=1||data[0]>1)return -1;g_cfg.mod_hyprx=data[0];return 0;
case 20:if(len!=1||data[0]>1)return -1;g_cfg.mod_leds=data[0];return 0;
case 21:if(len!=1||data[0]>1)return -1;g_cfg.mod_sof=data[0];return 0;
case 32:{if(len!=2)return -1;uint16_t v=data[0]|(data[1]<<8);if(v<100||v>32000)return -1;g_cfg.dpi=v;return 0;}
case 33:{if(len!=2)return -1;uint16_t v=data[0]|(data[1]<<8);if(v!=125&&v!=250&&v!=500&&v!=1000&&v!=2000&&v!=4000&&v!=8000)return -1;g_cfg.poll=v;return 0;}
case 34:if(len!=1||data[0]<1||data[0]>3)return -1;g_cfg.lod_mm=data[0];return 0;
case 35:if(len!=1||data[0]<10||data[0]>200)return -1;g_cfg.lod_squal=data[0];return 0;
case 36:if(len!=1||data[0]>1)return -1;g_cfg.angle_snap=data[0];return 0;
case 37:if(len!=1||data[0]>100)return -1;g_cfg.angle_strength=data[0];return 0;
case 38:if(len!=1||data[0]>3)return -1;g_cfg.surface=data[0];return 0;
case 48:if(len!=1||data[0]>20)return -1;g_cfg.db_pb3=data[0];return 0;
case 49:if(len!=1||data[0]>20)return -1;g_cfg.db_pb4=data[0];return 0;
case 50:if(len!=1||data[0]>20)return -1;g_cfg.db_pb5=data[0];return 0;
case 51:if(len!=1||data[0]>20)return -1;g_cfg.db_pb6=data[0];return 0;
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

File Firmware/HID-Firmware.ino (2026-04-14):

// BOOTLOADER_FLAG: Change 0x0 to 0x4000 when using a bootloader in build_opt.h

#include "system.h"
#include "usb.h"
#include "timer.h"
#include "pipeline.h"
#include "usb_hid.h"

void setup(void) {
  SystemClock_Config();
  delay(10);
  pipeline_init();
  usb_hid_init();
  usb_init();
  timer_init();
}

void loop(void) {
  if (usb_sof_detected()) {
    pipeline_report_t report;
    if (pipeline_get_ready_report(&report)) {
      usb_hid_send_report(report.buttons, report.wheel);
    }
  }
}

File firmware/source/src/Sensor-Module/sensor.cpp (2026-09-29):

#include "sensor.h"
#include "sensor_filter.h"
#include "srom_04.h"
#include "../Config-Module/config.h"
#include "../USB-Module/device.h"
#include <Arduino.h>
#include <SPI.h>
#include <stm32g4xx.h>
#define PIN_CS PA4
#define PIN_RST PA2
#define REG_Product_ID 0x00
#define REG_Motion 0x02
#define REG_Config1 0x0F
#define REG_Config2 0x10
#define REG_SROM_Enable 0x13
#define REG_SROM_ID 0x2A
#define REG_Power_Up_Reset 0x3A
#define REG_Motion_Burst 0x50
#define REG_SROM_Load_Burst 0x62
#define REG_Lift_Config 0x63
#define SF_N 8
#define SENSOR_HZ 8000u
#define BURST_LEN 7
#define LOD1_MARGIN 5
#define PEND_LIMIT 2032
#define SPI_SET SPISettings(2000000,MSBFIRST,SPI_MODE3)
static uint8_t ready=0;
static uint8_t idle=1;
static uint8_t locked=0;
static uint16_t last_fn=0xFFFF;
static uint32_t last_sof=0,t_next=0;
static sf_packet_t pk[SF_N];
static uint8_t np=0;
static int32_t pend_x=0,pend_y=0;
static float rem_x=0.0f,rem_y=0.0f;
static uint16_t ap_dpi=0,ap_cpi=800;
static uint8_t ap_lod=0;
static inline uint32_t cyc(void){return DWT->CYCCNT;}
static void dly_us(uint32_t us){uint32_t t=cyc(),n=us*(SystemCoreClock/1000000u);while((cyc()-t)<n){}}
static inline void cs_low(void){digitalWrite(PIN_CS,LOW);}
static inline void cs_high(void){digitalWrite(PIN_CS,HIGH);}
static uint8_t rreg(uint8_t a){
SPI.beginTransaction(SPI_SET);
cs_low();
SPI.transfer(a&0x7F);
dly_us(160);
uint8_t d=SPI.transfer(0);
dly_us(1);
cs_high();
SPI.endTransaction();
dly_us(30);
return d;
}
static void wreg(uint8_t a,uint8_t d){
SPI.beginTransaction(SPI_SET);
cs_low();
SPI.transfer(a|0x80);
SPI.transfer(d);
dly_us(35);
cs_high();
SPI.endTransaction();
dly_us(150);
}
static void apply_cfg(void){
uint16_t v=g_cfg.dpi/100u;
if(v<1)v=1;
if(v>120)v=120;
wreg(REG_Config1,(uint8_t)(v-1));
wreg(REG_Lift_Config,g_cfg.lod_mm>=3?0x03:0x02);
wreg(REG_Motion_Burst,0x00);
ap_dpi=g_cfg.dpi;
ap_lod=g_cfg.lod_mm;
ap_cpi=(uint16_t)(v*100u);
}
static void read_packet(sf_packet_t *q){
uint8_t d[BURST_LEN]={0};
SPI.beginTransaction(SPI_SET);
cs_low();
SPI.transfer(REG_Motion_Burst);
dly_us(36);
SPI.transfer(d,BURST_LEN);
cs_high();
SPI.endTransaction();
q->lifted=(d[0]&0x08)?1:0;
q->squal=d[6];
if(d[0]&0x80){
int16_t rx=(int16_t)((d[3]<<8)|d[2]);
int16_t ry=(int16_t)((d[5]<<8)|d[4]);
q->dx=(int16_t)-rx;
q->dy=(int16_t)-ry;
}else{
q->dx=0;q->dy=0;
}
}
static void flush(void){
sf_packet_t t;
read_packet(&t);
dly_us(130);
read_packet(&t);
sf_reset();
np=0;
}
static uint8_t try_init(void){
cs_high();
wreg(REG_Power_Up_Reset,0x5A);
delay(80);
for(uint8_t r=0x02;r<=0x06;r++)rreg(r);
delay(10);
if(rreg(REG_Product_ID)!=0x42)return 0;
wreg(REG_Config2,0x00);
delay(10);
wreg(REG_SROM_Enable,0x1D);
delay(10);
wreg(REG_SROM_Enable,0x18);
delay(10);
SPI.beginTransaction(SPI_SET);
cs_low();
SPI.transfer(REG_SROM_Load_Burst|0x80);
dly_us(15);
for(uint16_t i=0;i<SROM_04_LENGTH;i++){
SPI.transfer(SROM_04[i]);
dly_us(15);
}
cs_high();
SPI.endTransaction();
delay(30);
if(rreg(REG_SROM_ID)!=0x04)return 0;
ap_dpi=0;ap_lod=0;
apply_cfg();
wreg(REG_Config2,0x00);
delay(30);
rreg(REG_Motion);
delay(10);
wreg(REG_Motion_Burst,0x00);
return 1;
}
extern "C" {
void sensor_init(void){
ready=0;
pinMode(PIN_RST,OUTPUT);
digitalWrite(PIN_RST,HIGH);
delay(200);
pinMode(PIN_CS,OUTPUT);
cs_high();
delay(100);
SPI.setMISO(PA6);
SPI.setMOSI(PA7);
SPI.setSCLK(PA5);
SPI.begin();
delay(200);
for(uint8_t i=0;i<3&&!ready;i++)ready=try_init();
sf_reset();
idle=1;locked=0;np=0;last_fn=0xFFFF;
pend_x=pend_y=0;rem_x=rem_y=0.0f;
}
uint8_t sensor_ready(void){return ready;}
static void close_frame(void){
sf_params_t prm;
uint16_t sq=g_cfg.lod_squal;
if(g_cfg.lod_mm==1)sq+=LOD1_MARGIN;
prm.squal_min=(uint8_t)(sq>255?255:sq);
prm.dpi=ap_cpi;
prm.snap_en=g_cfg.angle_snap;
prm.snap_strength=g_cfg.angle_strength;
switch(g_cfg.surface){
case 1:prm.a_min=0.25f;break;
case 2:prm.a_min=0.35f;break;
default:prm.a_min=0.30f;break;
}
float ox,oy;
sf_frame(pk,np,&prm,&ox,&oy);
rem_x+=ox;rem_y+=oy;
int32_t ix=(int32_t)rem_x,iy=(int32_t)rem_y;
rem_x-=(float)ix;rem_y-=(float)iy;
pend_x+=ix;pend_y+=iy;
if(pend_x>PEND_LIMIT)pend_x=PEND_LIMIT;
if(pend_x<-PEND_LIMIT)pend_x=-PEND_LIMIT;
if(pend_y>PEND_LIMIT)pend_y=PEND_LIMIT;
if(pend_y<-PEND_LIMIT)pend_y=-PEND_LIMIT;
}
void sensor_task(void){
if(!ready)return;
uint32_t now=cyc();
if(!g_cfg.mod_sensor||!usb_device_configured()){
idle=1;np=0;locked=0;
pend_x=pend_y=0;rem_x=rem_y=0.0f;
return;
}
if(idle){
idle=0;
if(g_cfg.dpi!=ap_dpi||g_cfg.lod_mm!=ap_lod)apply_cfg();
flush();
now=cyc();t_next=now;last_fn=0xFFFF;
}else if(g_cfg.dpi!=ap_dpi||g_cfg.lod_mm!=ap_lod){
apply_cfg();
flush();
now=cyc();t_next=now;
}
uint16_t fn=USB->FNR&USB_FNR_FN;
if(fn!=last_fn){
last_fn=fn;
last_sof=now;
if(locked)close_frame();
np=0;t_next=now;locked=1;
}else if(locked&&(now-last_sof)>(SystemCoreClock/1000u)*3u){
locked=0;
}
if(np<SF_N&&(int32_t)(now-t_next)>=0){
read_packet(&pk[np++]);
t_next+=SystemCoreClock/SENSOR_HZ;
uint32_t n2=cyc();
if((int32_t)(n2-t_next)>0)t_next=n2;
}
if(!locked&&np>=SF_N){close_frame();np=0;}
}
void sensor_take(int16_t *dx,int16_t *dy){
int32_t x=pend_x,y=pend_y;
int32_t m=(x<0?-x:x);
int32_t my=(y<0?-y:y);
if(my>m)m=my;
if(m>127){
x=(x*127)/m;
y=(y*127)/m;
}
pend_x-=x;pend_y-=y;
*dx=(int16_t)x;*dy=(int16_t)y;
}
}

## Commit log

2026-04-09 First git commit: working HID enumeration + button clicks (uses standard mouse lib)
2026-04-14 Added scroll wheel logic
2026-05-26 up-to-date codebase
    [.stl, BOM.csv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]
2026-07-19 Cleaned up codebase and added many new things and improved workflow and updated everything. Firmware and docs is the only thing left.
    [.stl, BOM.csv, Cobalt-X_Zero_rev-3_bom.csv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]
2026-07-20 Added Git Repo To Github Repo
    [Cobalt-X_Zero_rev-3_bom.csv]
2026-07-27 Added some 3D models, and cleaned up Firmware
    [Cobalt-X_Zero_rev-3_positions.csv, CustomMouse.kicad_pcb, CustomMouse.kicad_sch]
2026-07-27 Most of HID firmware done, SENSOR module is left, and some way to config the mouse (perhaps not MSC) is still underway
    [Bottom-Shell.stl, Cobalt-X_Zero.kicad_pcb, Cobalt-X_Zero.kicad_sch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]
2026-07-30 Fixed a few things and finalized stuff
    [Bottom-Shell.stl, Scroll-Wheel.stl, Side-Buttons.stl]
2026-09-24 Repo structure remastered, and all up-to-date
    [.stl, Bottom-Plate.stl, Cobalt-X_Zero.kicad_pcb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]
2026-09-24 Stop tracking private/WIP folders and files that should be ignored
    [pmw3360_pcb_ffc.kicad_pcb, pmw3360_pcb_ffc.kicad_sch, pmw3360_pcb_jst.kicad_pcb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]
2026-09-28 config fixing and test
    [clock.cpp, config.cpp, config.h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]
2026-09-29 good site
    [Bottom-Plate.stl, PCB-Holder.stl, Scroll-Wheel.stl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]
2026-09-29 revert firmware + sie
    [clock.cpp, config.cpp, config.h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]
2026-09-29 Revert "Firmware Finished, Docs Mostly Finished"
    This reverts commit d2a607134f547a7b2123f38767d85372205bc45b.
    [clock.cpp, config.cpp, config.h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]
2026-09-29 reverted to working firmware + config site
    [clock.cpp, config.cpp, config.h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]
